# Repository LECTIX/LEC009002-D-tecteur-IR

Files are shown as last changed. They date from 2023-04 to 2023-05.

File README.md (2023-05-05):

# LEC009002 - Détecteur IR
Fichiers sources pour le produit LEC009002

## Description du produit

- Distance de détection réglable jusqu’à 10 cm
- Fonctionne même à la lumière du jour!
- Temporisation à la désactivation pour éviter des réactivations intempestives.
- 2 modes de fonctionnements :

1. **Mode direct (1 capteur)** le relais est commuté lorsqu’un objet se trouve en face du capteur. Le relais est relâché lorsqu’il n’y a plus d’obstacles devant le capteur.
2. **Mode bistable (2 capteurs)** Le relais est relâché lorsqu’un objet passe devant le second capteur.

## Utiliser les fichiers sources pour fabriquer le produit

Grâce aux fichiers sources publiés ici, vous pouvez être en mesure de faire fabriquer ce produit par un sous traitant.

**ATTENTION** ce produit est un **produit complexe à fabriquer** et nécessite notamment une programmation afin de pouvoir fonctionner. Vous devez pour cela posséder le programmateur et programmer vous même la carte. Cette étape peut nécessiter des connaissances techniques, si nécessaire, nous vous encourrageons à vous rapprocher d'un club.

**Remarque** ce produit est composé d'une carte mère, de 2 nappes de cable IDC 6 pin, et de 2 capteurs. Ce dossier permet uniquement de faire fabriquer la carte mère et les capteurs, vous devrez vous fournir les autres composants sur un site de revente (amazon, aliexpress, mouser, ...).

**Remarque 2** vous avez le choix entre 1 capteur coudé ou 1 capteur classique. Notez cependant que pour le capteur classique, le sous traitant JLCPCB n'est pas capable de souder le capteur sur le côté du PCB, vous devrez donc opter pour le capteur coudé si vous ne souhaitez pas souder vous même.

### Faire fabriquer chez un sous traitant

Il est aujourd'hui possible de faire fabriquer à moindre cout des cartes électroniques. Nous recommendons [JLCPCB](https://jlcpcb.com/) si vous voulez aller au moins cher. Si vous préférez un acteur européen, [eurocircuits](https://www.eurocircuits.com/) est un des acteurs reconnus.

IMAGE ALT TEXT (http://www.youtube.com/watch?v=RXGGvsUtz0c "TUTO : faire fabriquer un produit LECTIX")

1. Télécherger les sources de ce produit en cliquant sur le bouton `Code`, puis `Download ZIP`.
1. Décompresser le dossier.
1. Les fichiers pour la fabrication se trouvent dans le répertoire `hardware/prod`.
1. Se connecter sur [https://cart.jlcpcb.com/quote](https://cart.jlcpcb.com/quote)
1. Cliquer sur le bouton `Add gerber file` et sélectionner le fichier `gerbers.zip`.
1. Sélectionnez la quantité de cartes que vous souhaitez dans le champs `PCB Qty`.
1. Laisser toutes les autres options par défaut, puis cliquez sur le toggle switch en face de `PCB Assembly`, et enfin sur le bouton `confirm`.
1. Une preview de la carte électronique sans les composants doit apparaitre. Cliquez sur `NEXT`.
1. Cliquez sur le bouton `Add BOM File`, puis sélectionnez le fichier `bom.csv`
1. Cliquez sur le bouton `Add CPL File`, puis sélectionnez le fichier `pos.csv`
1. **Vérifier que tous les composants sont en stock** et bien sélectionnés, puis cliquez sur `NEXT`.
1. Une preview de la carte avec ses composants apparait. Continuer le chemin en cliquant sur `NEXT`.
1. Le prix final apparait. Sélectionnez la catégorie du produit, puis cliquez sur `SAVE TO CART`.
1. Une fois sauvegardé dans votre panier, vous pouvez valider votre commande et choisir le moyen d'acheminement. Afin de ne pas avoir à se préoccuper des frais de douane, nous vous conseillons de choisir une méthode d'expédition DDP.

Vous receverez vos cartes sous 1 à 3 semaines. 

**Nous ne sommes en aucun cas responsables des cartes qui arriveraient défectueuses ou non fonctionnelles.**

### Modifications des fichiers sources

Installez kicad 6 (ou version supérieure), et ouvrez le fichier LEC009002.kicad_pro

### Programation

Pour programmer le module, vous devez posséder
- un programmateur AVR type USBASP
- Des fils pour relier le programmateur avec les points de programmation. (**Note importante** : cette carte ne possède pas de connecteur de programmation. Pour la programmer, il vous faudra soit utiliser le banc de programmation pour lequel vous souderez des pogo pins, soit trouver un moyen de relier les fils du programmateur à la carte directement)

Le firmware se trouve dans le dossier du même nom. Il est recommandé d'utiliser VS-code et platform-io pour programmer la carte. Pour ce faire, branchez le programmateur à votre PC et à la carte à programmer, puis rentrer les commandes suivantes :

```
cd firmware
platformio run --target fuses && platformio run --target upload
```

### Regénérer les fichiers gerber, BOM, et position (Optionnel)

Peut se faire simplement en utilisant kikit :

```
cd hardware/carte-mere
docker run --rm -w /kikit -v $PWD:/kikit yaqwsx/kikit kikit fab jlcpcb --assembly --no-drc --schematic LEC009002.kicad_sch --field LCSC --corrections JLCPCB_CORRECTION --nametemplate LEC009002_{} LEC009002.kicad_pcb prod/

cd hardware/capteur-droit
docker run --rm -w /kikit -v $PWD:/kikit yaqwsx/kikit kikit fab jlcpcb --assembly --no-drc --schematic LEC009202.kicad_sch --field LCSC --corrections JLCPCB_CORRECTION --nametemplate LEC009202_{} LEC009202.kicad_pcb prod/

cd hardware/capteur-coude
docker run --rm -w /kikit -v $PWD:/kikit yaqwsx/kikit kikit fab jlcpcb --assembly --no-drc --schematic LEC009212.kicad_sch --field LCSC --corrections JLCPCB_CORRECTION --nametemplate LEC009212_{} LEC009212.kicad_pcb prod/
```
## Notices
[Manuel FR](docs/manual_fr.pdf)

## License
Tous nos fichiers sont plubliés sous les licenses
- CERN Open Hardware Licence Version 2 - Strongly Reciprocal pour ce qui touche au hardware
- GNU General Public License v3.0 pour tout ce qui est software

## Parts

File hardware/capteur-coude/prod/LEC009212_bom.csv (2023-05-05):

Comment | Designator | Footprint | LCSC
C601936 | J1 | Connector_IDC:IDC-Header_2x03_P2.54mm_Vertical | C601936
DY-ITR20001 | U1 | 0_ITR:DY-ITR20001 | C459137

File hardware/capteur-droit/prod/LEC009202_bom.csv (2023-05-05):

Comment | Designator | Footprint | LCSC
C601936 | J1 | Connector_IDC:IDC-Header_2x03_P2.54mm_Vertical | C601936

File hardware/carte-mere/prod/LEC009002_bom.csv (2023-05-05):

Comment | Designator | Footprint | LCSC
100nF | C1,C3,C4 | Capacitor_SMD:C_0603_1608Metric | C14663
100uF | C2,C5 | 0_capacitors:CP_Elec_6.3x5.8 | C249982
MB10S | D1 | Package_TO_SOT_SMD:TO-269AA | C2488
LED | D2 | LED_SMD:LED_0603_1608Metric | C72043
D | D3 | Diode_SMD:D_SMA | C95872
PWR | J1 | 0_connectors:TerminalBlock_bornier-2_P5.08mm-green | C395849
CONTACT_1 | J3 | 0_connectors:TerminalBlock_bornier-3_P5.08mm-blue | C395881
CONTACT2 | J4 | 0_connectors:TerminalBlock_bornier-3_P5.08mm-blue | C395881
IDC6 | J5,J6 | Connector_IDC:IDC-Header_2x03_P2.54mm_Vertical | C11214
HK19F-5V | K1 | 0_relays:Relay_DPDT_HK19F | C54512
S8050 | Q1,Q2,Q3 | Package_TO_SOT_SMD:SOT-23 | C2146
10k | R1,R5 | Resistor_SMD:R_0603_1608Metric | C25804
1k | R2,R3,R4,R8,R9 | Resistor_SMD:R_0603_1608Metric | C21190
100 | R6,R7 | Resistor_SMD:R_0603_1608Metric | C22775
100k | RV1,RV2 | 0_potentiometers:Potentiometer_Bourns_TC33X_Vertical | C128545
ATtiny24A-SSU | U1 | Package_SO:SOIC-14_3.9x8.7mm_P1.27mm | C8726
MC78M05_TO252 | U2 | Package_TO_SOT_SMD:TO-252-2 | C58069

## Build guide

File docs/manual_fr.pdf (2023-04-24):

# Détecteur IR pour trains

### LEC009002

## 1 Caractéristiques

- 2 modes de fonctionnements :

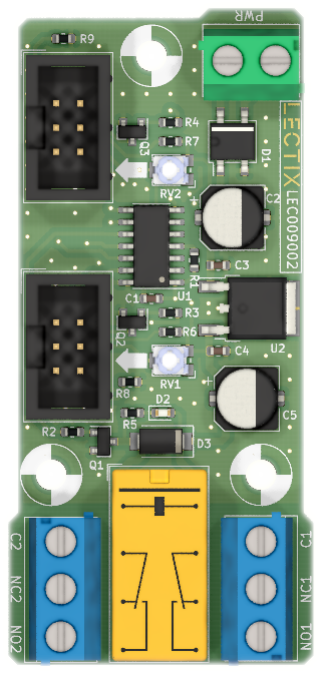
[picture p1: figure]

– Mode direct (1 capteur) : le relais est commuté lorsqu’un objet se trouve en face du capteur. Le relais est relâché lorsqu’il n’y a plus d’obstacles devant le capteur.

– Mode bistable (2 capteurs) : le relais est commuté lorsqu’un objet passe devant un des deux capteurs. Le relais est relâché lorsqu’un objet passe devant le second capteur.

- Distance de détection réglable jusqu’à 10 cm.
- Possède un relais à 2 contacts inverseurs indépendants pour y brancher n’importe quel système.
- Peu sensible à la lumière du jour.
- Témoin lumineux d’activation.
- Temporisation à la désactivation pour éviter des réactivations intempestives.
- 3 trous de fixation pour un montage facile.

## 2 Applications

- Automatismes (passage à niveau, déclenchement d’un bruitage,...).
- Signalisation.
- Boucle de retournement.
- Gestion de voies cachée.

## 3 Spécifications technique

Specification | Valeur | Unité
Distance de détection | 0 - 10 | cm
Tension d’alimentation | 8 - 20 | V DC
Consommation (1 capteur) (2 capteurs) | 30 - 75 50 - 90 | mA mA
Pouvoir de coupure du relais | 1A 125V AC 2A 30V DC | -

Table 1 – Spécifications
LEC009002 - Détecteur IR pour trains rev 1.0.0 | 1

## 4 Dimensions

### 4.1 Dimension du module

Le module dispose de trois trous de fixation permeant de faire passer des vis de 3 mm.

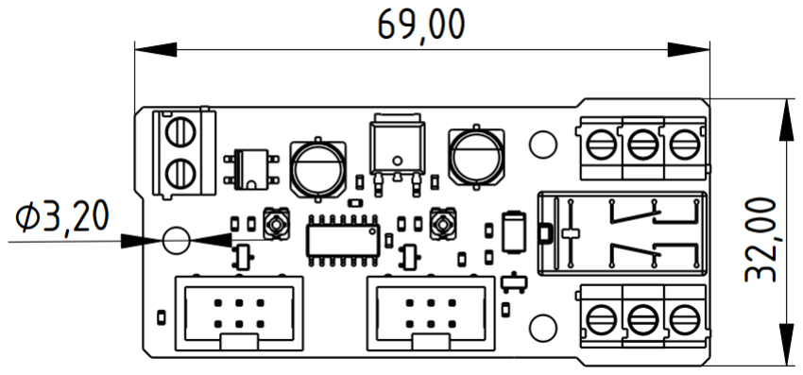
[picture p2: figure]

Figure 1 – Dimensions du module (toutes les côtes sont données en mm).

### 4.2 Dimension des capteurs

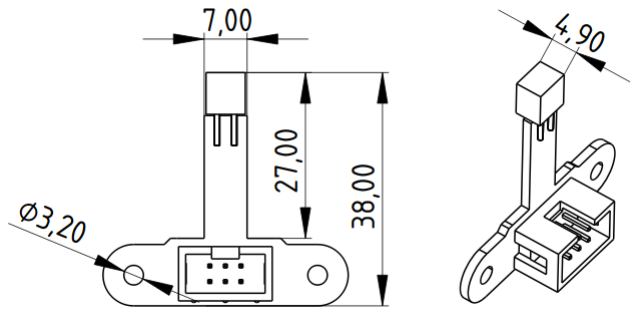
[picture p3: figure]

Figure 2 – Dimensions du capteur IR (toutes les côtes sont données en mm).

## 5 Utilisation

Le détecteur infra-rouge (IR) LEC009002 permet de détecter lorsqu’un train, wagon, ou tout autre objet passe devant un capteur. La forme des capteurs a été judicieusement pensée pour pouvoir les dissimuler facilement dans le décor ou sous une voie. Il est aussi possible de régler la distance de détection désirée pour chaque capteur, ce qui vous assurera un fonctionnement optimal quel que soit votre cas d’usage.

Selon que l’on branche un seul ou bien deux capteurs, le module aura un fonctionnement diérent. Ces 2 modes sont détaillés ci dessous.

### 5.1 Installation et câblage du module

Pour mere en route ce module, il suit de connecter une alimentation entre 8 et 20 V DC au bornier d’alimentation et le tour est joué! Le borner d’alimentation n’est pas polarisé, vous pouvez donc brancher le - et le + de l’alimentation comme bon vous semble. Il ne vous restera plus qu’à brancher le ou les capteurs via le câble fourni et votre module sera prêt à l’emploi.

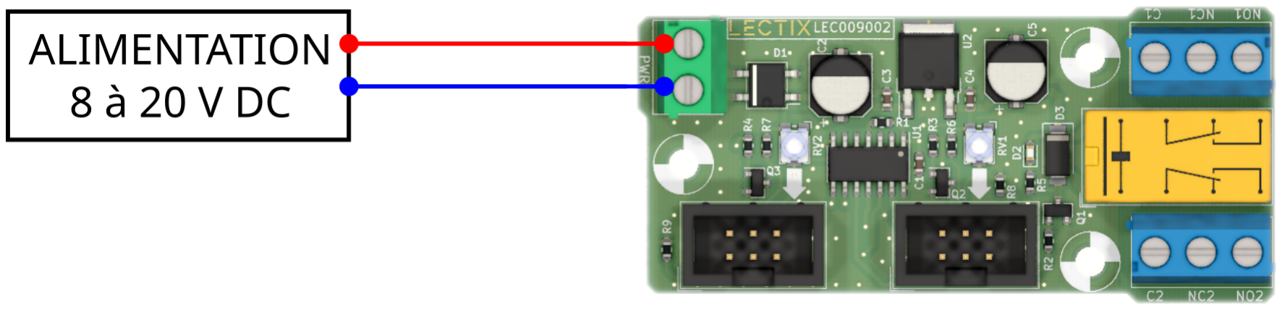
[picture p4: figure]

Figure 3 – Schéma de câblage du module.

Une fois le module installé, vous pouvez brancher un système ou un automatisme à activer grâce aux contacts inverseurs du relais (Cf. Figure 4). Vous trouverez des exemples d’utilisation à la fin de ce manuel.

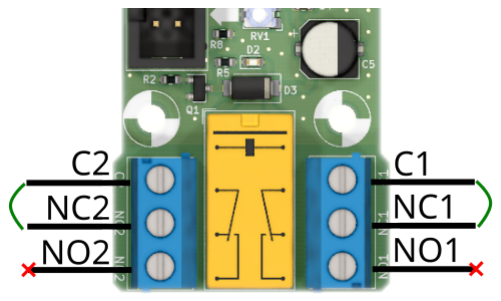
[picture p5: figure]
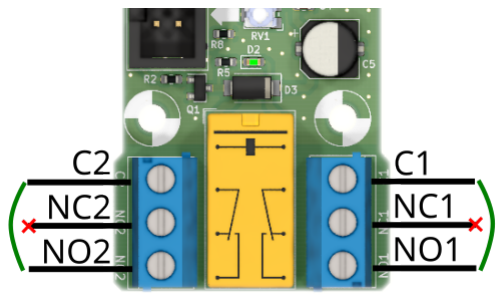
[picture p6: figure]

(a) Relais désactivé. | (b) Relais activé.

Figure 4 – Description des contacts inverseurs du relais.

5.2 Mode de fonctionnement à 1 capteur.

Lorsqu’un seul capteur est branché au module, quel que soit le connecteur auquel il est raccordé, le détecteur IR est en mode direct. Dans ce mode, le relais sera enclenché dès lors qu’un objet passe devant le capteur. Lorsque l’objet sort du champ de vision du capteur, le relais sera relâché après une courte temporisation. Cee temporisation permet d’éviter des enclenchements intempestifs liés à une discontinuité de l’objet détecté (exemple : l’espacement entre des wagons).

5.3 Mode de fonctionnement à 2 capteurs.

Lorsque 2 capteurs sont branchés au module, celui-ci est alors dans un mode bistable. Dans ce mode, le détecteur enclenchera le relais dès lors qu’un objet passe devant 1 des 2 capteurs. Le relais ne sera relâché que lorsque l’objet passera dans le champ de vision du deuxième capteur.

5.4 Régler la distance de détection des capteurs.

La distance de détection peut varier selon la couleur de l’objet qui passe devant le capteur. Pour vous assurer d’un fonctionnement optimal, il est recommandé d’eectuer ce réglage avec un objet de couleur noir. La distance de détection pourra alors se régler en plaçant l’objet à la distance désirée du capteur, et en ajustant délicatement le potentiomètre associé à chaque capteur comme indiqué sur la Figure 5. Pour plus d’aisance, il est recommandé d’eectuer ce réglage avec un seul capteur branché à la fois.

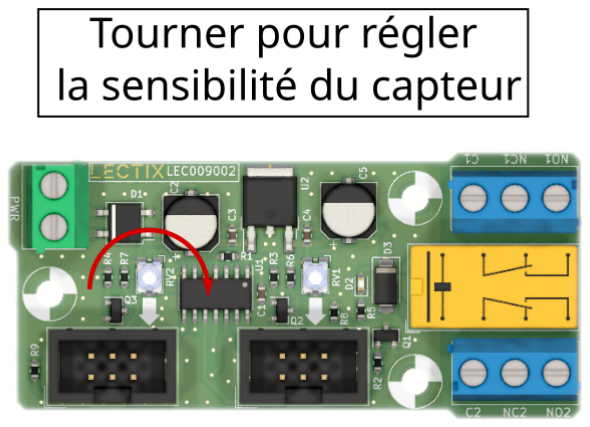
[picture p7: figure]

Figure 5 – Réglage de la sensibilité d’un capteur.

Pour diminuer la distance de détection, tourner le potentiomètre dans le sens des aiguilles d’une montre.
Pour augmenter la distance de détection, tourner le potentiomètre dans le sens inverse des aiguilles d’une montre.

☞ Note : Le potentiomètre est très fragile. NE jamais forcer dessus pour ne pas détériorer ou rendre inopérable le module.

### 5.5 Exemples d’utilisation

Les contacts inverseur du relais du module permeent une utilisation très générique. Voici quelques exemples d’utilisation.

### 5.5.1 Déclenchement d’un signal sonore (Klaxon, ...)

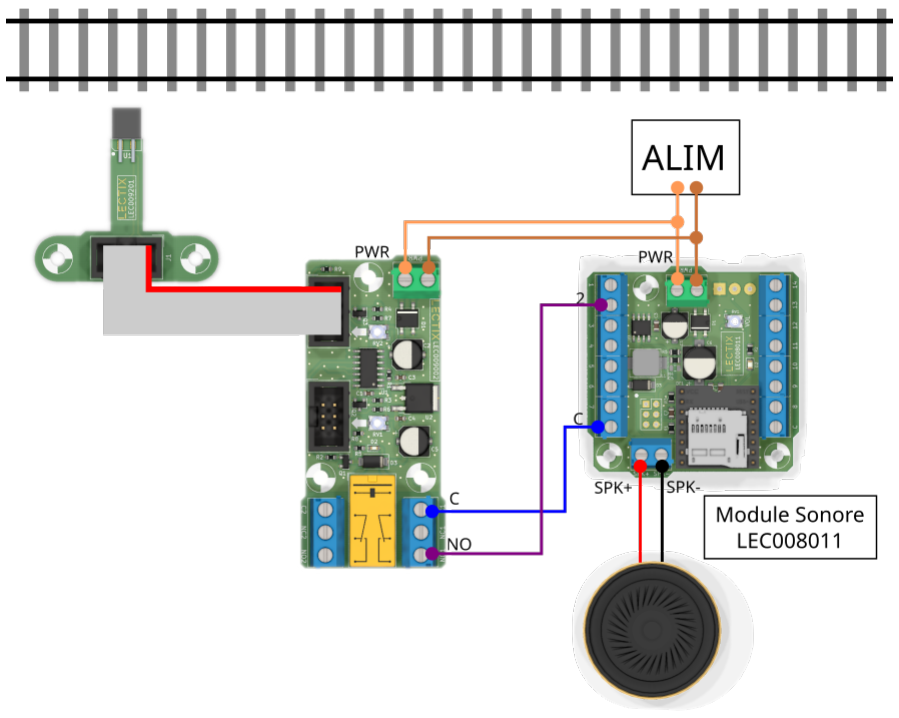
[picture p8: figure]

Figure 6 – Déclenchement d’un signal sonore.

## 6 Contact et SAV

Pour tout renseignement, veuillez vous adresser à contact@lectix.fr.

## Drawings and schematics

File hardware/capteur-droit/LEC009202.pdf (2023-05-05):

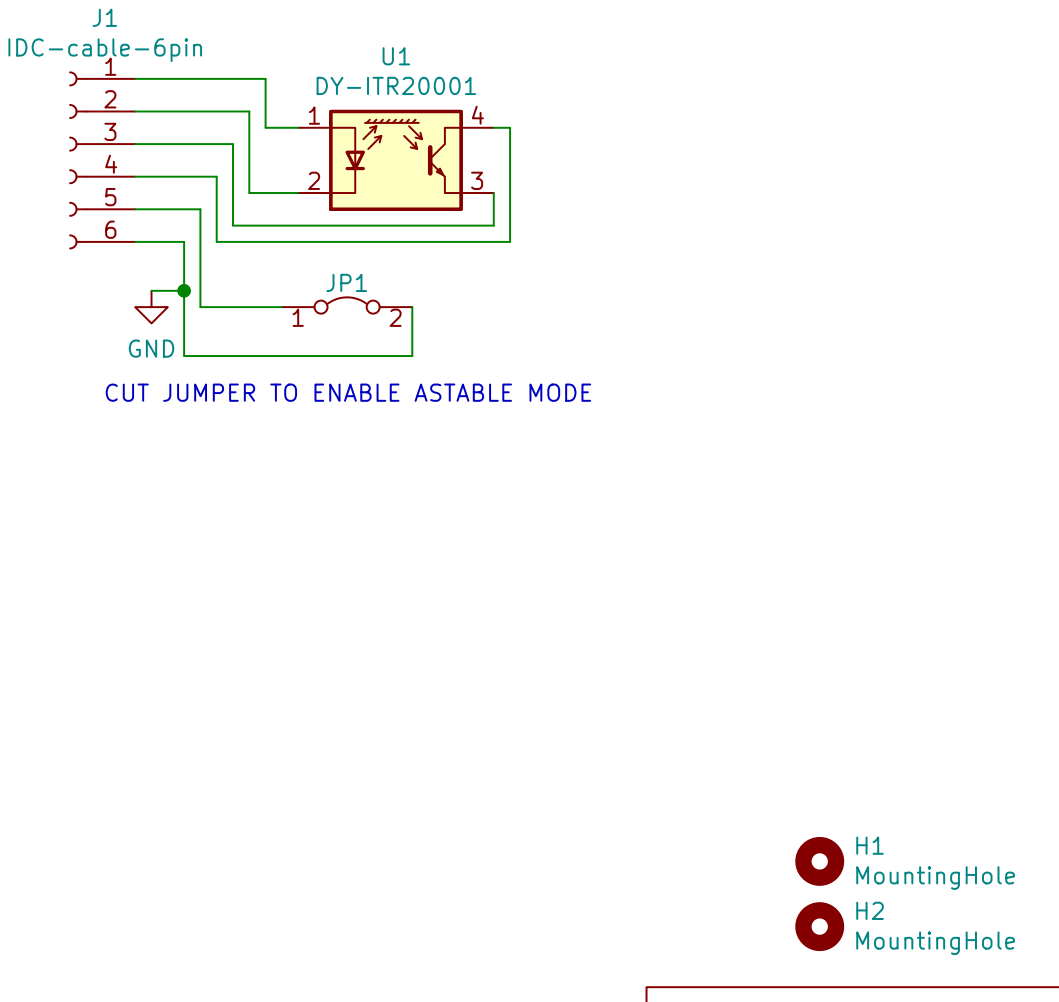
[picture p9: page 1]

CUT JUMPER TO ENABLE ASTABLE MODE

Id: 1/1 Title: LEC009202 - Capteur IR droit

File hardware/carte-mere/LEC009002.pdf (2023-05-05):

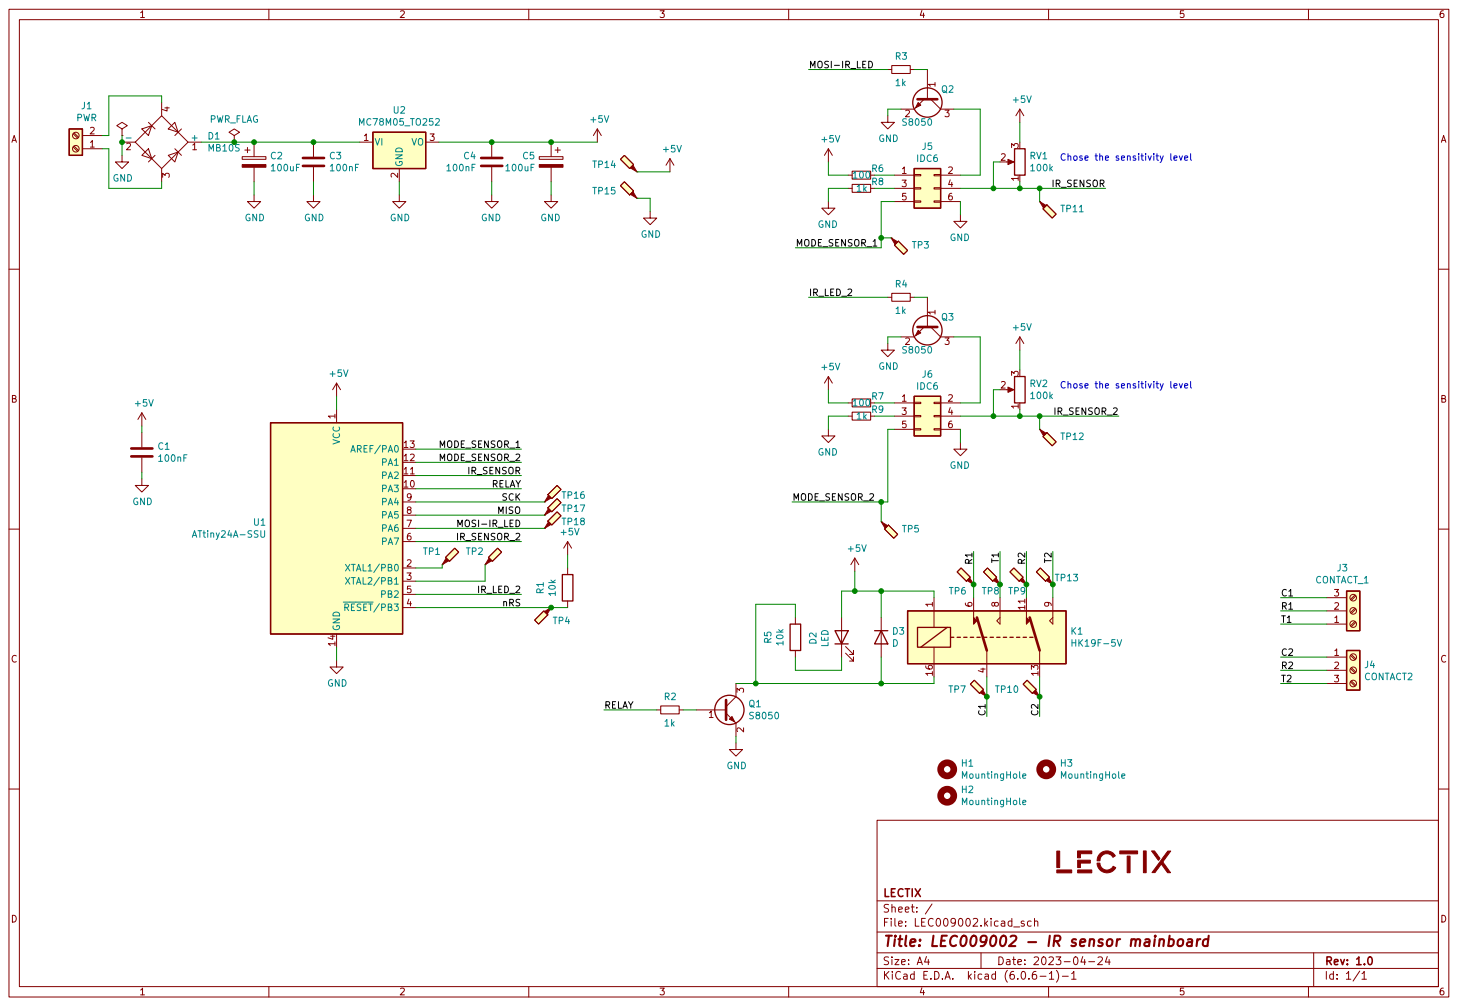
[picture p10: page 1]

Chose the sensitivity level

1 PA3 10 PA2 11 PA1 12 AREF/PA0 13 GND 14 XTAL1/PB0 2 XTAL2/PB1 3 ~{RESET}/PB3 4 PB2 5 PA7 6 PA6 7 PA5 8 PA4 9 U1 ATtiny24A-SSU R5 10k D2 LED

Id: 1/1 Title: LEC009002 - IR sensor mainboard

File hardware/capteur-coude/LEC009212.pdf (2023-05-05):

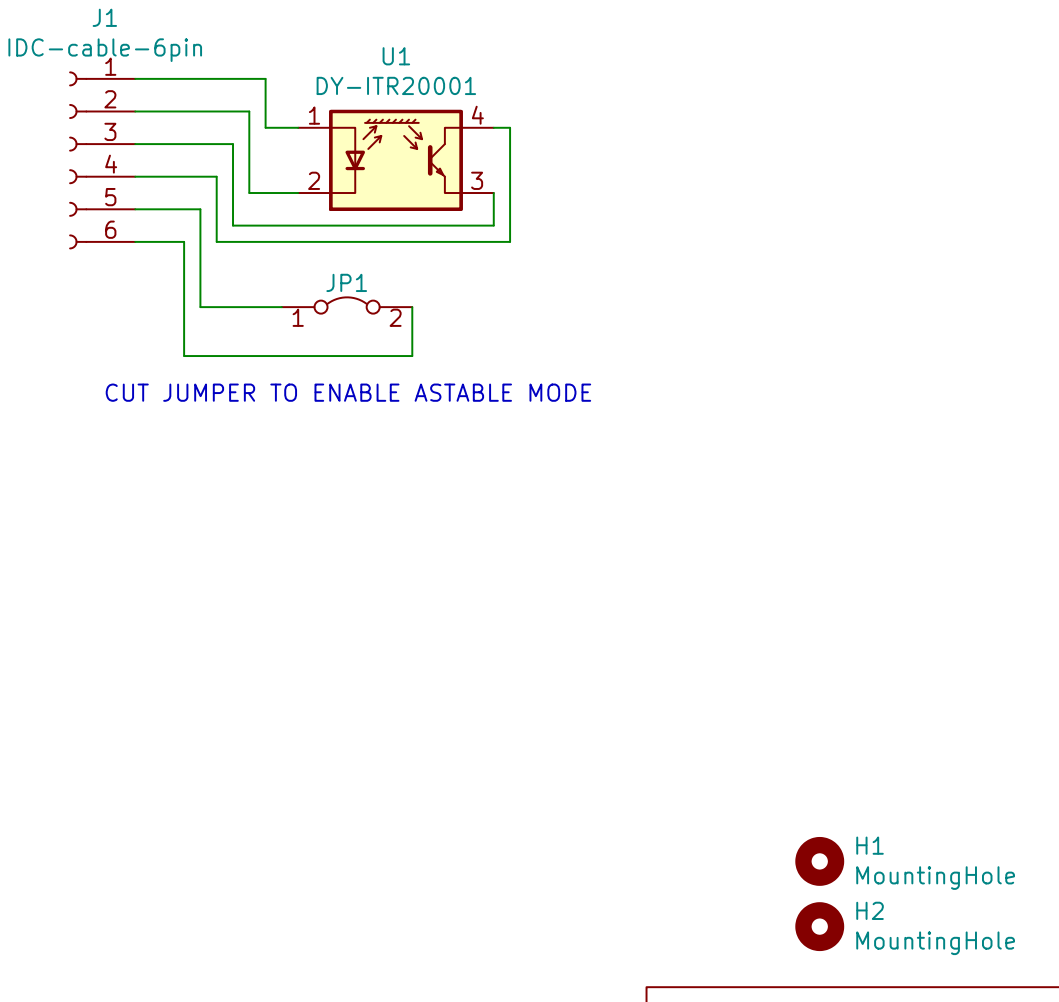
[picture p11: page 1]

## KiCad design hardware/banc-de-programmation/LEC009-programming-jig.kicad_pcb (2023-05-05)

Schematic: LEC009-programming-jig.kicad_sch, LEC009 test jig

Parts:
H1, H2, H3: MountingHole; MountingHole_3.2mm_M3; LCSC DNP
J1: Conn_01x18_Female; PinHeader_1x18_P2.54mm_Vertical
LOGO1: logo_lectix_25mm; Logo_10mm; LCSC DNP
TP1, TP2, TP3, TP4, TP5, TP6, TP7, TP8, TP9, TP10, TP11, TP12, TP13, TP14, TP15, TP16, TP17, TP18: TestPoint_Probe; pogo-1mm; LCSC DNP

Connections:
/+5V: J1.9, TP14.1
/C1: J1.6, TP7.1
/C2: J1.5, TP10.1
/GND: J1.18, TP15.1
/IR_SENSOR: J1.8, TP11.1
/IR_SENSOR_2: J1.16, TP12.1
/MISO: J1.14, TP17.1
/MODE_SENSOR_1: J1.7, TP3.1
/MODE_SENSOR_2: J1.15, TP5.1
/MOSI-IR_LED: J1.17, TP18.1
/PB0: J1.10, TP1.1
/PB1: J1.11, TP2.1
/R1: J1.4, TP6.1
/R2: J1.3, TP9.1
/SCK: J1.13, TP16.1
/T1: J1.2, TP8.1
/T2: J1.1, TP13.1
/nRS: J1.12, TP4.1

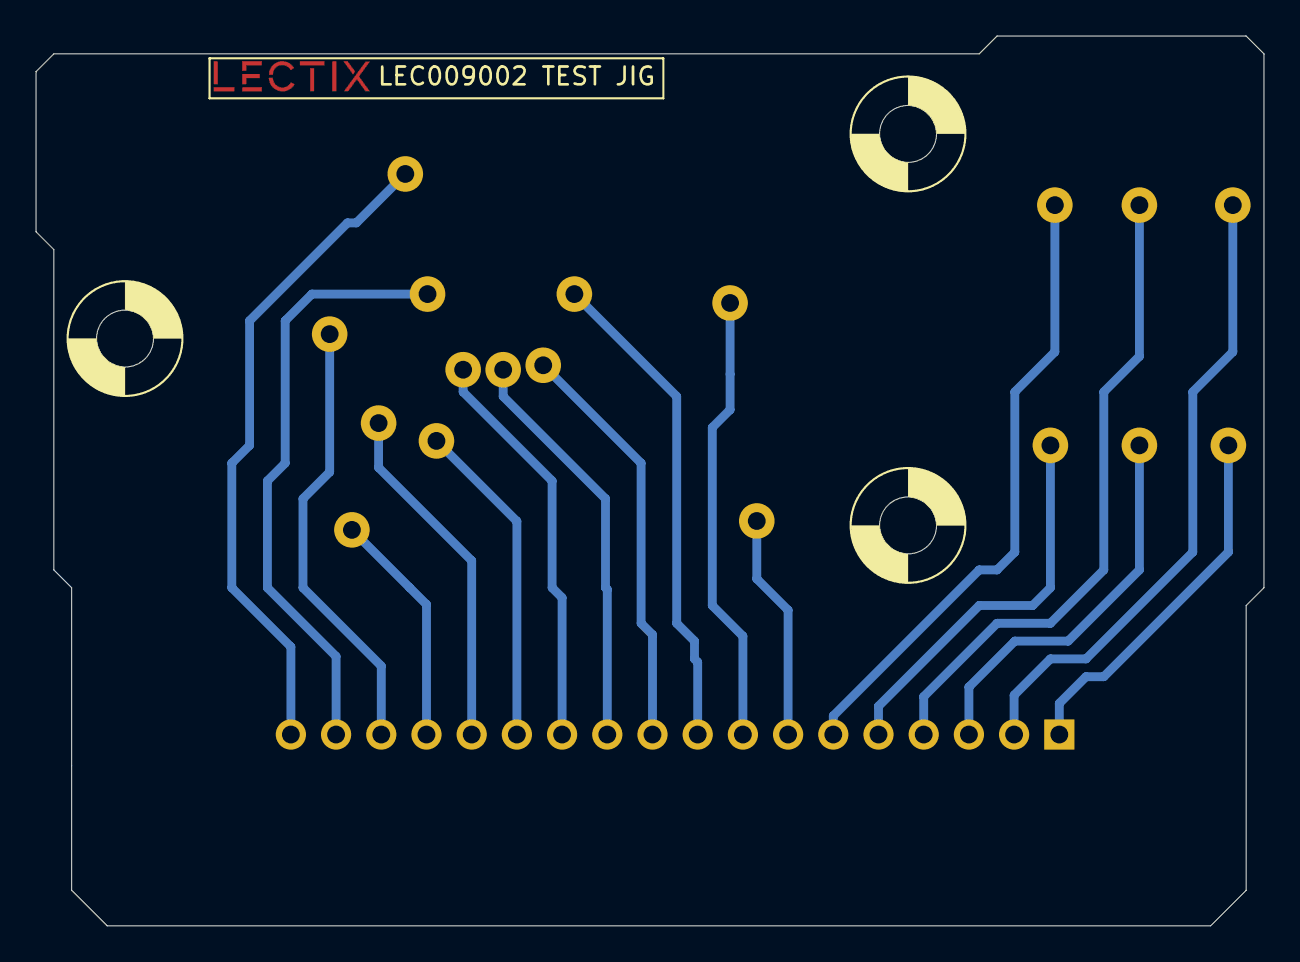
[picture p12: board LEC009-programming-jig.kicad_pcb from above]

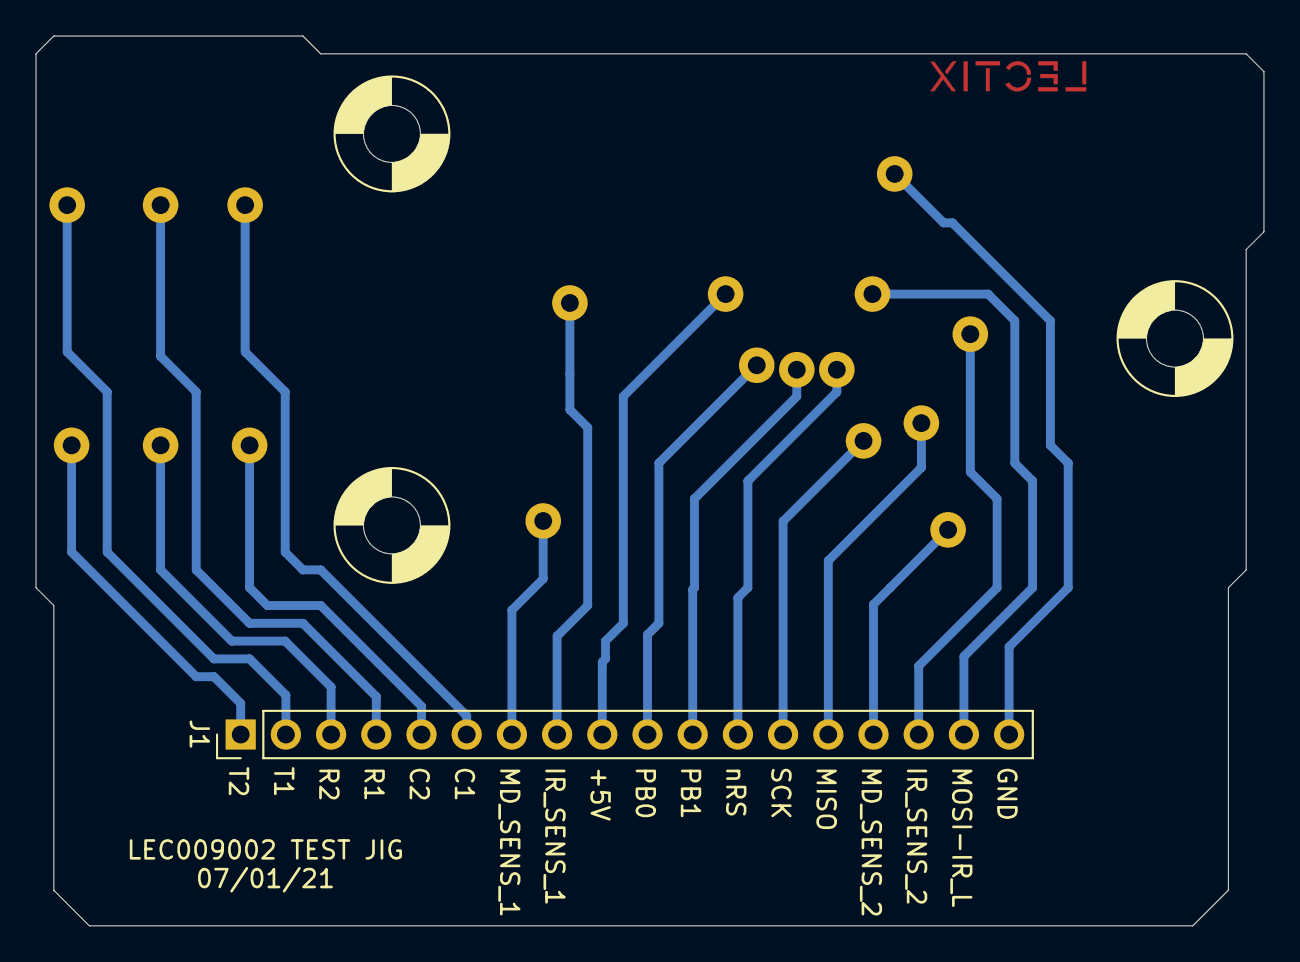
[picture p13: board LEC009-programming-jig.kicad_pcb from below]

Board: 2 copper layers, 69.0 x 50.0 mm, 23 parts (19 on the bottom side), 18 nets.

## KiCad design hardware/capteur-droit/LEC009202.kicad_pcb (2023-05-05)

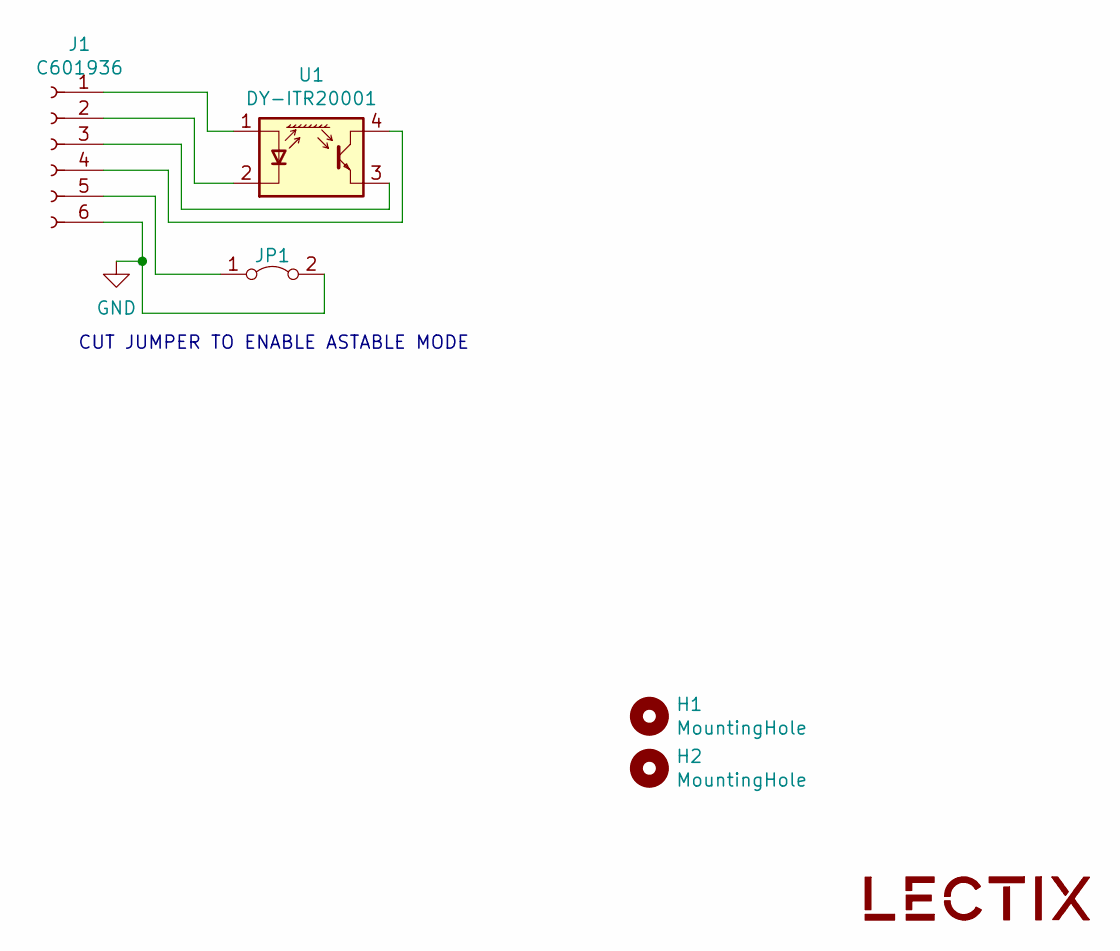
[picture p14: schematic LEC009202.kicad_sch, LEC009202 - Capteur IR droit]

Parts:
H1, H2: MountingHole; MountingHole_3.2mm_M3; PartNumber DNP; LCSC DNP
J1: C601936; IDC-Header_2x03_P2.54mm_Vertical; PartNumber 321006SG0ABK00A01; LCSC C601936
JP1: Jumper_2_Bridged; SolderJumper-2_P1.3mm_Bridged_RoundedPad1.0x1.5mm; PartNumber DNP
LOGO1: logo_lectix_25mm; Logo_10mm; PartNumber DNP; LCSC DNP
U1: DY-ITR20001; DY-ITR20001_edge; MPN DY-ITR20001; LCSC C459137

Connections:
GND: J1.6, JP1.2 (B)
unnamed: J1.1, U1.1 (A)
unnamed: J1.2, U1.2 (K)
unnamed: J1.3, U1.3
unnamed: J1.4, U1.4
unnamed: J1.5, JP1.1 (A)

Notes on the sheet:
CUT JUMPER TO ENABLE ASTABLE MODE

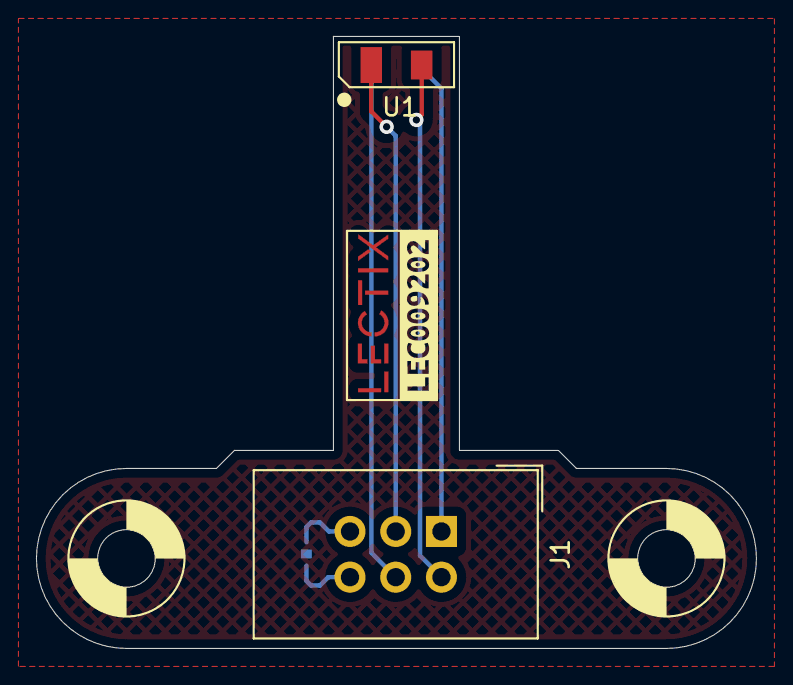
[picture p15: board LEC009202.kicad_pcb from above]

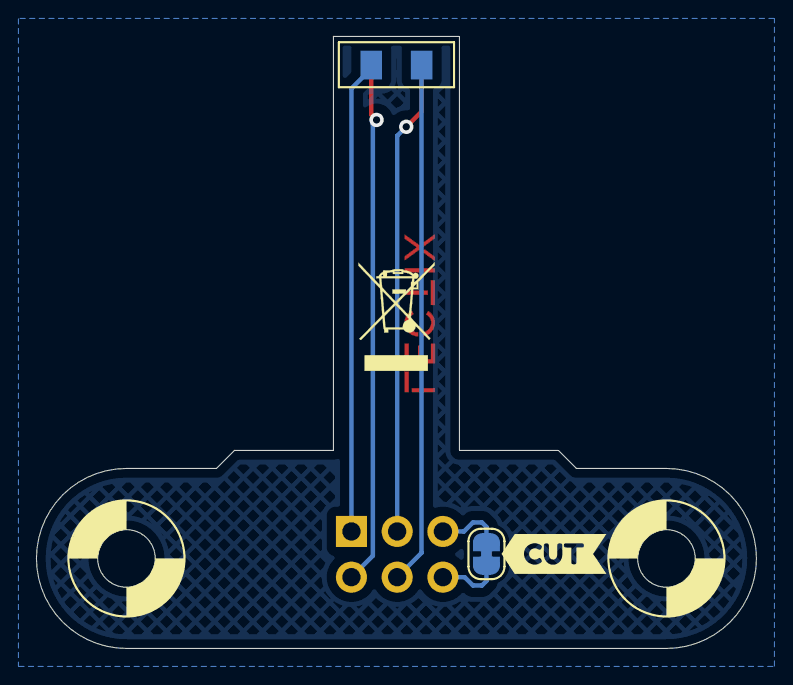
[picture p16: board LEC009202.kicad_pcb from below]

Board: 2 copper layers, 40.0 x 34.0 mm, 8 parts (2 on the bottom side), 6 nets.

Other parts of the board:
kibuzzard-620CD483: G***; kibuzzard-620CD483
kibuzzard-6239F921: G***; kibuzzard-6239F921

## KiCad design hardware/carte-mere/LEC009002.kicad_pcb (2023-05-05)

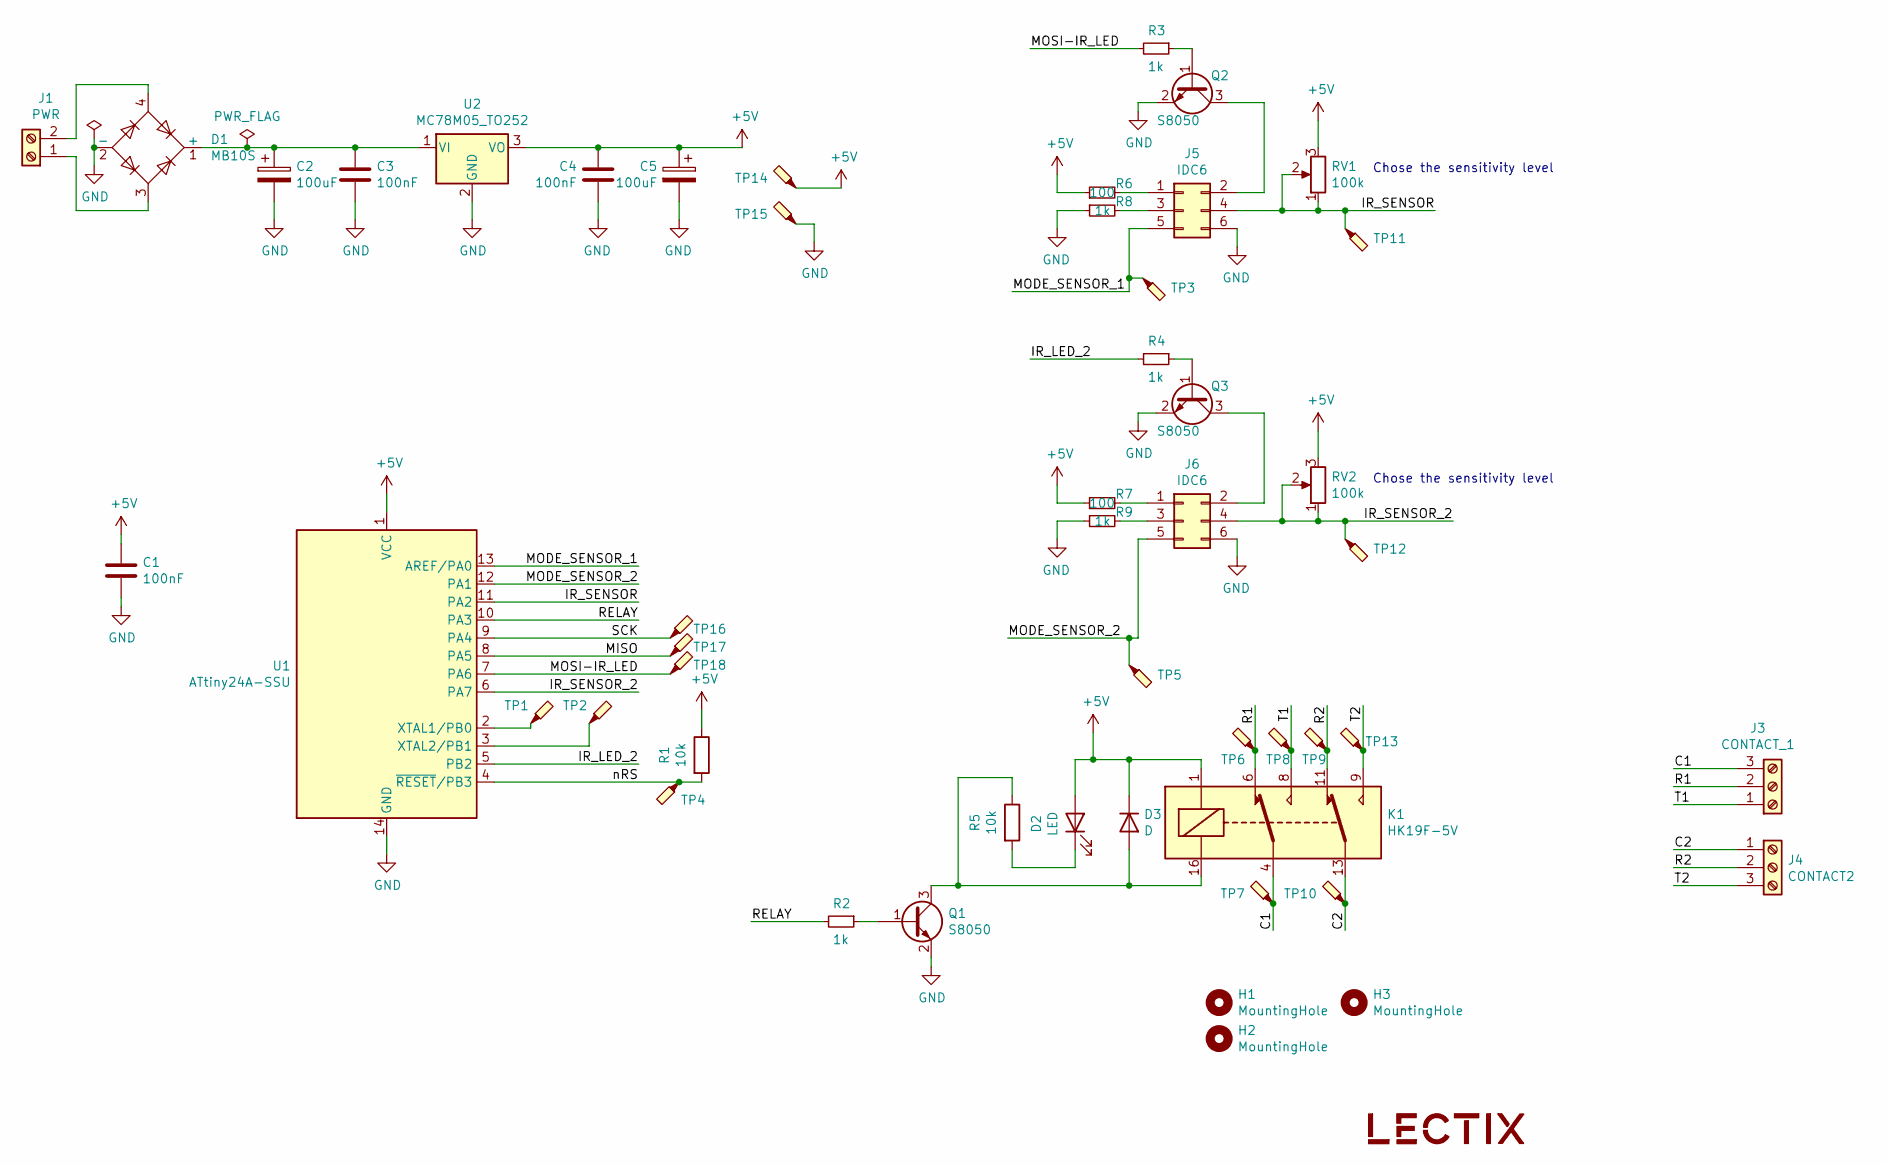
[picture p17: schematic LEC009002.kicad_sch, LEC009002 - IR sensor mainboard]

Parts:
C1, C3, C4: 100nF; C_0603_1608Metric; LCSC C14663
C2, C5: 100uF; CP_Elec_6.3x5.8; LCSC C249982
D1: MB10S; TO-269AA; LCSC C2488
D2: LED; LED_0603_1608Metric; LCSC C72043
D3: D; D_SMA; LCSC C95872
H1, H2, H3: MountingHole; MountingHole_3.2mm_M3; LCSC DNP
J1: PWR; TerminalBlock_bornier-2_P5.08mm-green; LCSC C395849
J3: CONTACT_1; TerminalBlock_bornier-3_P5.08mm-blue; LCSC C395881
J4: CONTACT2; TerminalBlock_bornier-3_P5.08mm-blue; LCSC C395881
J5, J6: IDC6; IDC-Header_2x03_P2.54mm_Vertical; LCSC C11214
K1: HK19F-5V; Relay_DPDT_HK19F; LCSC C54512
LOGO1: logo_lectix_25mm; Logo_10mm; LCSC DNP
Q1, Q2, Q3: S8050; SOT-23; LCSC C2146
R1, R5: 10k; R_0603_1608Metric; LCSC C25804
R2, R3, R4, R8, R9: 1k; R_0603_1608Metric; LCSC C21190
R6, R7: 100; R_0603_1608Metric; LCSC C22775
RV1, RV2: 100k; Potentiometer_Bourns_TC33X_Vertical; LCSC C128545
TP1, TP2, TP3, TP4, TP5, TP6, TP7, TP8, TP9, TP10, TP11, TP12, TP13, TP14, TP15, TP16, TP17, TP18: TestPoint_Probe; TestPoint_Pad_D1.5mm; LCSC DNP
U1: ATtiny24A-SSU; SOIC-14_3.9x8.7mm_P1.27mm; LCSC C8726
U2: MC78M05_TO252; TO-252-2; LCSC C58069

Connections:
+5V: C1.1, C4.1, C5.1, D2.2 (A), D3.1 (K), K1.1, R1.1, R6.1, R7.1, RV1.3, RV2.3, TP14.1, U1.1 (VCC), U2.3 (VO)
/C1: J3.3, K1.4, TP7.1
/C2: J4.1, K1.13, TP10.1
/IR_LED_2: R4.2, U1.5 (PB2)
/IR_SENSOR: J5.4, RV1.1, RV1.2, TP11.1, U1.11 (PA2)
/IR_SENSOR_2: J6.4, RV2.1, RV2.2, TP12.1, U1.6 (PA7)
/MISO: TP17.1, U1.8 (PA5)
/MODE_SENSOR_1: J5.5, TP3.1, U1.13 (AREF/PA0)
/MODE_SENSOR_2: J6.5, TP5.1, U1.12 (PA1)
/MOSI-IR_LED: R3.2, TP18.1, U1.7 (PA6)
/R1: J3.2, K1.6, TP6.1
/R2: J4.2, K1.11, TP9.1
/RELAY: R2.2, U1.10 (PA3)
/SCK: TP16.1, U1.9 (PA4)
/T1: J3.1, K1.8, TP8.1
/T2: J4.3, K1.9, TP13.1
/nRS: R1.2, TP4.1, U1.4 (~RESET/PB3)
GND: C1.2, C2.2, C3.2, C4.2, C5.2, D1.2 (-), J5.6, J6.6, Q1.2 (E), Q2.2 (E), Q3.2 (E), R8.1, R9.1, TP15.1, U1.14 (GND), U2.2 (GND)
unnamed: C2.1, C3.1, D1.1 (+), U2.1 (VI)
unnamed: D1.3, J1.1
unnamed: D1.4, J1.2
unnamed: D2.1 (K), R5.2
unnamed: D3.2 (A), K1.16, Q1.3 (C), R5.1
unnamed: J5.1, R6.2
unnamed: J5.2, Q2.3 (C)
unnamed: J5.3, R8.2
unnamed: J6.1, R7.2
unnamed: J6.2, Q3.3 (C)
unnamed: J6.3, R9.2
unnamed: Q1.1 (B), R2.1
unnamed: Q2.1 (B), R3.1
unnamed: Q3.1 (B), R4.1
unnamed: TP1.1, U1.2 (XTAL1/PB0)
unnamed: TP2.1, U1.3 (XTAL2/PB1)

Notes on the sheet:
Chose the sensitivity level

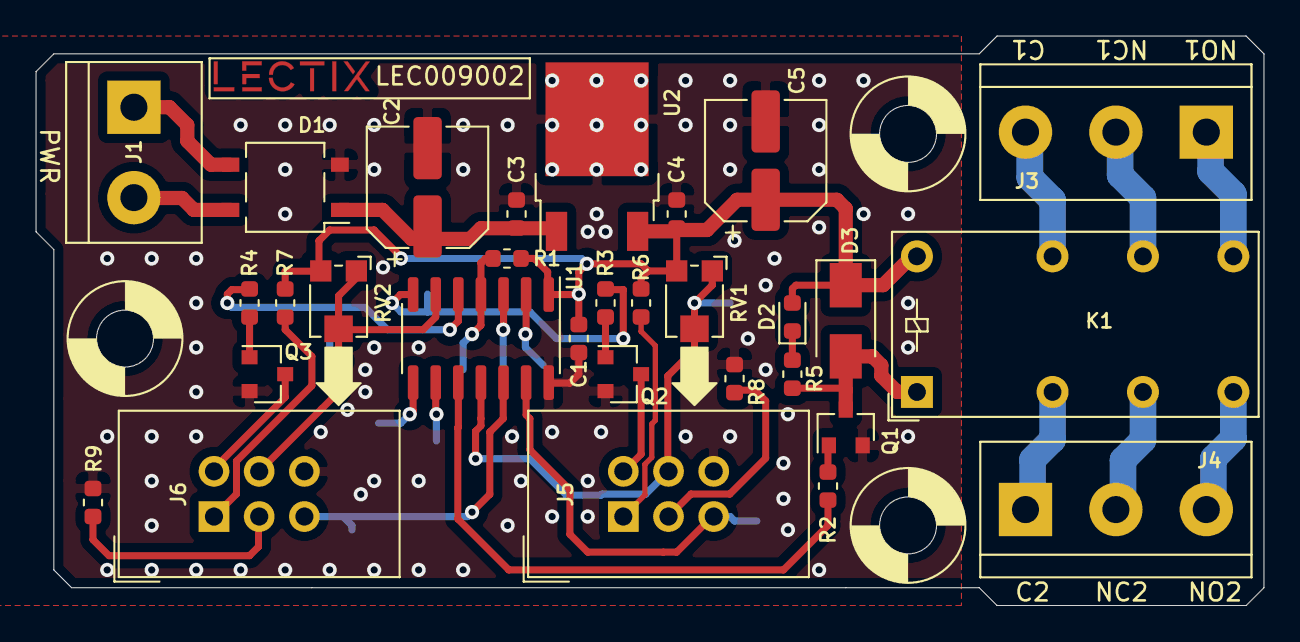
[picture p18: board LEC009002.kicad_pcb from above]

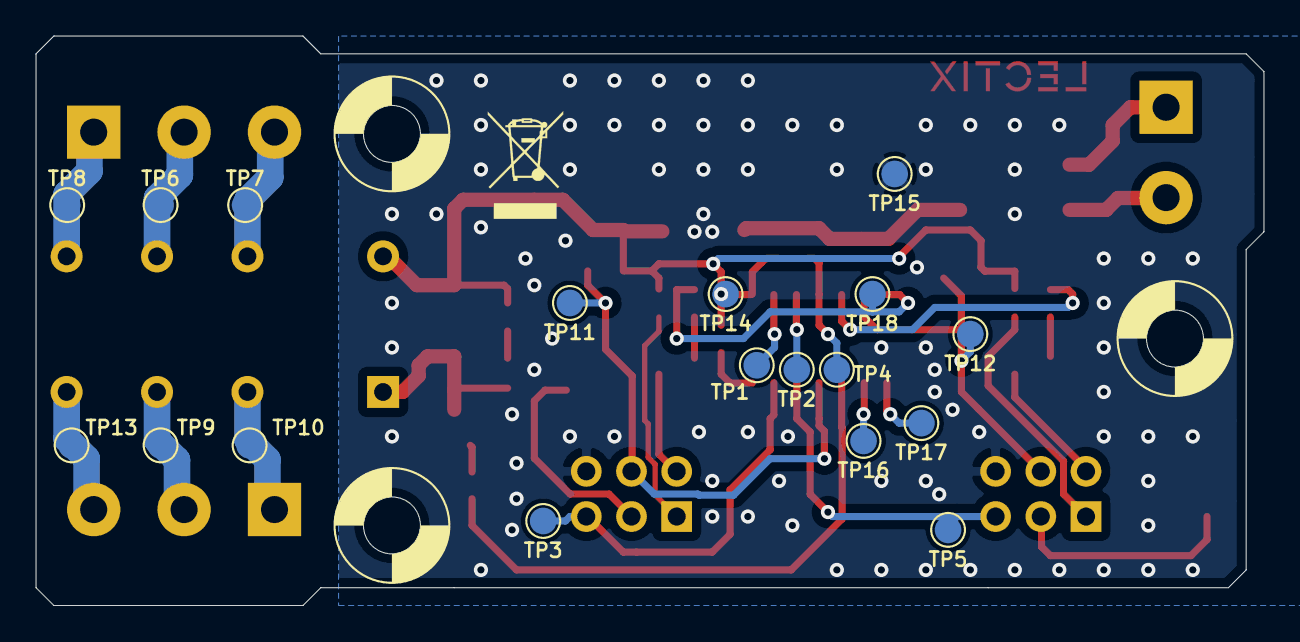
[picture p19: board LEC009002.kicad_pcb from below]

Board: 2 copper layers, 69.0 x 32.0 mm, 52 parts (18 on the bottom side), 34 nets.

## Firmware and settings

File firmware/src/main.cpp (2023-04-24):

#include <Arduino.h>
#include "constants.h"

// Return true if sensor is triggered
bool updateSensor(const int ledPin, const int sensorPin)
{
    bool ret = false;
    digitalWrite(ledPin, HIGH);  /* turn ON IR LED */
    delay(1);                    /* wait for everything to stabilize */
    if (!digitalRead(sensorPin)) /* if sensor pin is low, there is maybe something */
    {
        digitalWrite(ledPin, LOW); /* turn OFF IR LED */
        delay(1);                  /* and repeat test to make sure it wasn't a false trigger */
        if (digitalRead(sensorPin))
        {
            digitalWrite(ledPin, HIGH);
            delay(1);
            if (!digitalRead(sensorPin))
                ret = true;
        }
    }
    digitalWrite(ledPin, LOW);
    return ret;
}

void setup()
{
    pinMode(PIN_IR_LED_1, OUTPUT);
    pinMode(PIN_IR_LED_2, OUTPUT);
    pinMode(PIN_IR_SENSOR_1, INPUT);
    pinMode(PIN_IR_SENSOR_2, INPUT);
    pinMode(PIN_SENSOR1_MODE, INPUT_PULLUP);
    pinMode(PIN_SENSOR2_MODE, INPUT_PULLUP);
    pinMode(PIN_RELAY, OUTPUT);
}

enum STATE
{
    WAITING_TRIGGER,
    TRIGGERED_SENSOR_1,
    TRIGGERED_SENSOR_2,
    WAITING_SENSOR_1_DEACTIVATION,
    WAITING_SENSOR_2_DEACTIVATION
};

STATE state = WAITING_TRIGGER;
uint32_t lastTriggerTmstp = 0;

void loop()
{
    bool sensor1 = updateSensor(PIN_IR_LED_1, PIN_IR_SENSOR_1);
    bool sensor2 = updateSensor(PIN_IR_LED_2, PIN_IR_SENSOR_2);

    if (digitalRead(PIN_SENSOR1_MODE)^digitalRead(PIN_SENSOR2_MODE)) /* only 1 sensor plugged in */
    {
        if (sensor1 || sensor2)
        {
            digitalWrite(PIN_RELAY, HIGH);
            lastTriggerTmstp = millis();
        }
        else if (millis() - lastTriggerTmstp > MODE_1_SENSOR_TIMEOUT)
        {
            digitalWrite(PIN_RELAY, LOW);
        }
    }
    else /* Both sensors are plugged in */
    {
        switch (state)
        {
        case WAITING_TRIGGER:
            if (sensor1)
                state = TRIGGERED_SENSOR_1;
            if (sensor2)
                state = TRIGGERED_SENSOR_2;
            break;

        case TRIGGERED_SENSOR_1:
            digitalWrite(PIN_RELAY, HIGH);
            if (sensor2)
            {
                digitalWrite(PIN_RELAY, LOW);
                lastTriggerTmstp = millis();
                state = WAITING_SENSOR_2_DEACTIVATION;
            }
            break;

        case TRIGGERED_SENSOR_2:
            digitalWrite(PIN_RELAY, HIGH);
            if (sensor1)
            {
                digitalWrite(PIN_RELAY, LOW);
                lastTriggerTmstp = millis();
                state = WAITING_SENSOR_1_DEACTIVATION;
            }
            break;

        case WAITING_SENSOR_1_DEACTIVATION:
            if (sensor1)
                lastTriggerTmstp = millis();
            else if (millis() - lastTriggerTmstp > MODE_2_SENSOR_TIMEOUT)
                state = WAITING_TRIGGER;
            break;

        case WAITING_SENSOR_2_DEACTIVATION:
            if (sensor2)
                lastTriggerTmstp = millis();
            else if (millis() - lastTriggerTmstp > MODE_2_SENSOR_TIMEOUT)
                state = WAITING_TRIGGER;
            break;

        default:
            state = WAITING_TRIGGER;
            break;
        }
    }

    // delay(1000);
    // digitalWrite(PIN_RELAY,!digitalRead(PIN_RELAY));
}

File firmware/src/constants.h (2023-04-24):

#ifndef CONSTANTS_H
#define CONSTANTS_H

#define MODE_1_SENSOR_TIMEOUT 1000 /* timeout in ms */
#define MODE_2_SENSOR_TIMEOUT 1000 /* timeout in ms */

#define PIN_IR_LED_1 4
#define PIN_IR_SENSOR_2 3
#define PIN_SENSOR1_MODE 10
#define PIN_SENSOR2_MODE 9
#define PIN_IR_SENSOR_1 8
#define PIN_IR_LED_2 2
#define PIN_RELAY 7

#endif

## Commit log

2023-05-05 Add hardware source files
    [LEC009002-CmtUser.gbr, LEC009002-CuBottom.gbl, LEC009002-CuTop.gtl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]
2023-05-05 Add programming jig
    [LEC009-programming-jig.kicad_pcb, LEC009-programming-jig.kicad_sch]
